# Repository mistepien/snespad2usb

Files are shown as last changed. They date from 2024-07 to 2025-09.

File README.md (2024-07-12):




# snespad2usb
SNES gampepad adapter to USB.

<a href="https://github.com/mistepien/snespad2usb/blob/main/snespad2usb.pdf">Adapter</a> is actually a shield for 
<a href="https://learn.sparkfun.com/tutorials/pro-micro--fio-v3-hookup-guide/hardware-overview-pro-micro">Arduino Pro Micro based on ATmega 32U4</a>.

ATmega 32U4 has a hardware support for fullspeed USB, thus <a href="https://wiki.archlinux.org/title/mouse_polling_rate">polling rate 1000Hz</a> is not an issue for that chip.

You can use the <a href="https://github.com/mistepien/snespad2usb/tree/main/production">gerber file<a> to order the PCB.

Attached <a href="https://github.com/mistepien/snespad2usb/tree/main/firmware">code</a> uses port registers so that is quite efficient. The code was tested with <a href="https://www.8bitdo.com/sn30-wireless-for-original-snes-sfc/">SN30 2.4g wireless gamepad for original SNES/SFC</a> and original SNES and SFC gamepads. Everything works flawless!

One footprint is not trivial: SNES gamapad socket (<b>J1</b>). Footprint is DIY.

<b>J2</b> is redundant -- you can use it to add some new features like autofire switch or sth.

Sometimes during uploading code to Arduino board you may face some issues -- then you will need to use RESET -- so <b>SW1</b> can be useful if you like to develope your own code.

SW2 can be usefull to have a so-called "Hot key" -- you can need it eg. in Batocera.

LED D1 shows is SNES gamepad connected at all. LED D2 is just a status LED (turn on in setup() function of firmware).

BOM:
| Qty	| Reference(s) | Description |
|-----|---|---|
|2 | D1, D2 | LEDs 3mm |  
|1 | J1| SNES gamepad make connector |
|1 | J2| 2x4 Pinheader. pitch terminal: 2.54mm |
|1 | R1, R2 | resistors for D1 and D2 |
|1 | R3 | 10KΩ PULL-UP resistor for DATA gamepad pin |
|1 | SW1,SW2 | Tact switches from Arduino breadboard projects |
|1 | U1 | DIP20 socket (width 15.24mm) + <a href="https://learn.sparkfun.com/tutorials/pro-micro--fio-v3-hookup-guide/hardware-overview-pro-micro">Arduino Pro Micro</a> |

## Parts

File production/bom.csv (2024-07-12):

Designator | Footprint | Quantity | Value | LCSC Part #
D1 | LED_D3.0mm_Oval | 1 | CTL-ON
D2 | LED_D3.0mm_Oval | 1 | STATUS
J1 | SNES_gamepad_connector_L_horizontal | 1 | SNES-GAMEPAD-SOCKET
J2 | PinHeader_2x04_P2.54mm_Vertical | 1 | Conn_02x04_Odd_Even
R1, R2 | R_Axial_DIN0207_L6.3mm_D2.5mm_P10.16mm_Horizontal_Oval | 2 | RxΩ
R3 | R_Axial_DIN0207_L6.3mm_D2.5mm_P10.16mm_Horizontal_Oval | 1 | R10KΩ
SW1 | SW_PUSH_6mm_H4.3mm | 1 | RST
SW2 | SW_PUSH_6mm_H4.3mm | 1 | HOT KEY
U1 | DIP-24_W15.24mm_Socket_LongPads | 1 | Arduino_Pro_Micro

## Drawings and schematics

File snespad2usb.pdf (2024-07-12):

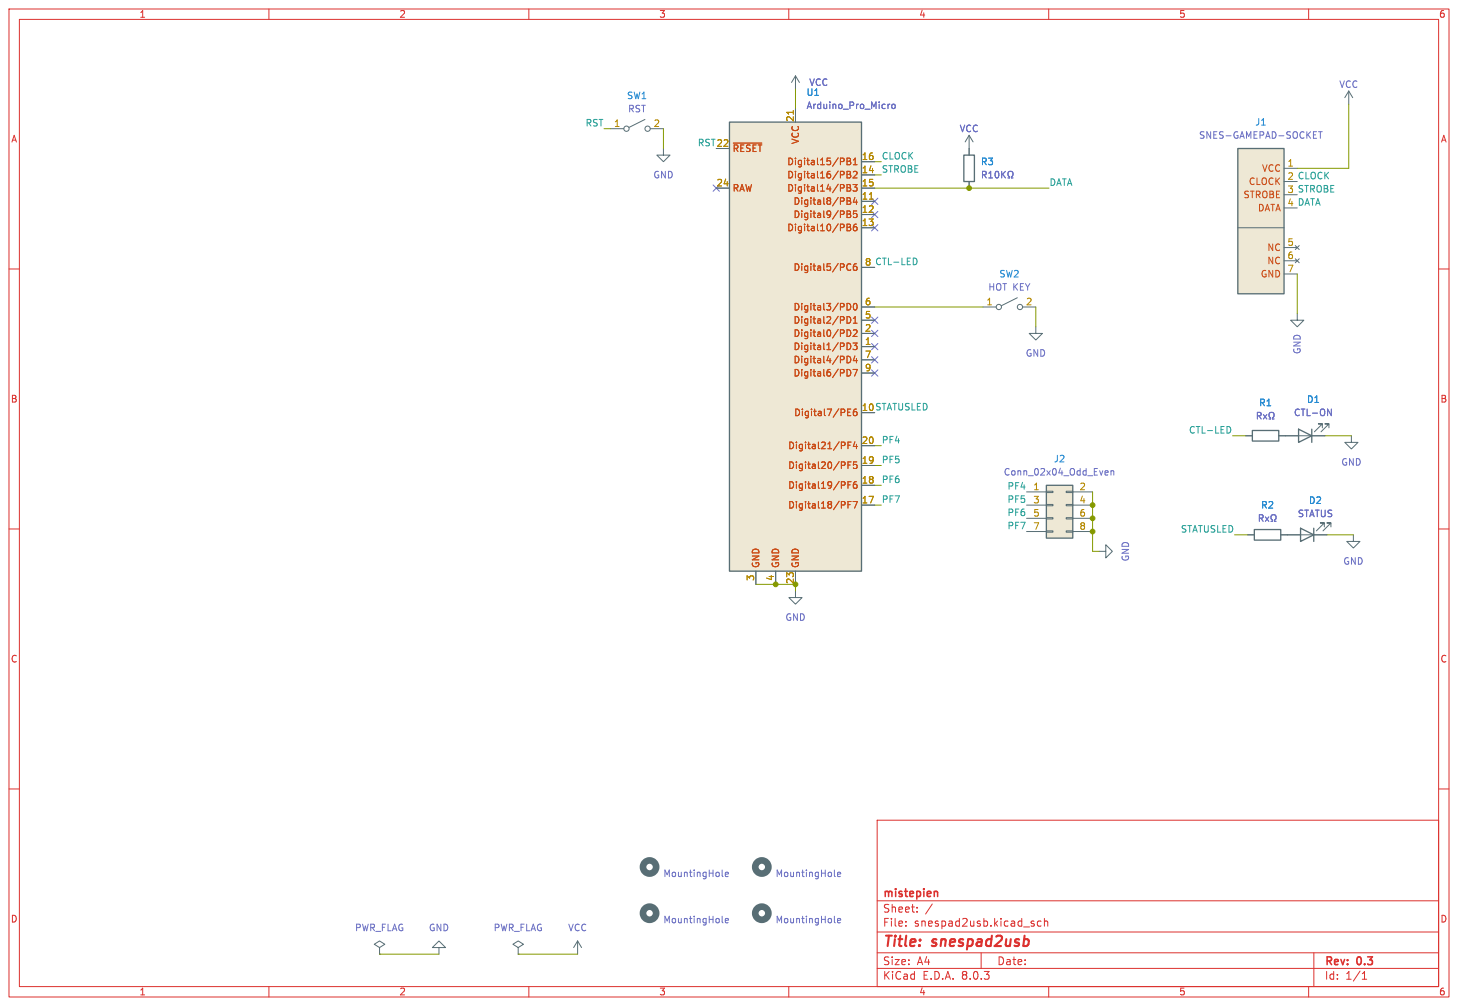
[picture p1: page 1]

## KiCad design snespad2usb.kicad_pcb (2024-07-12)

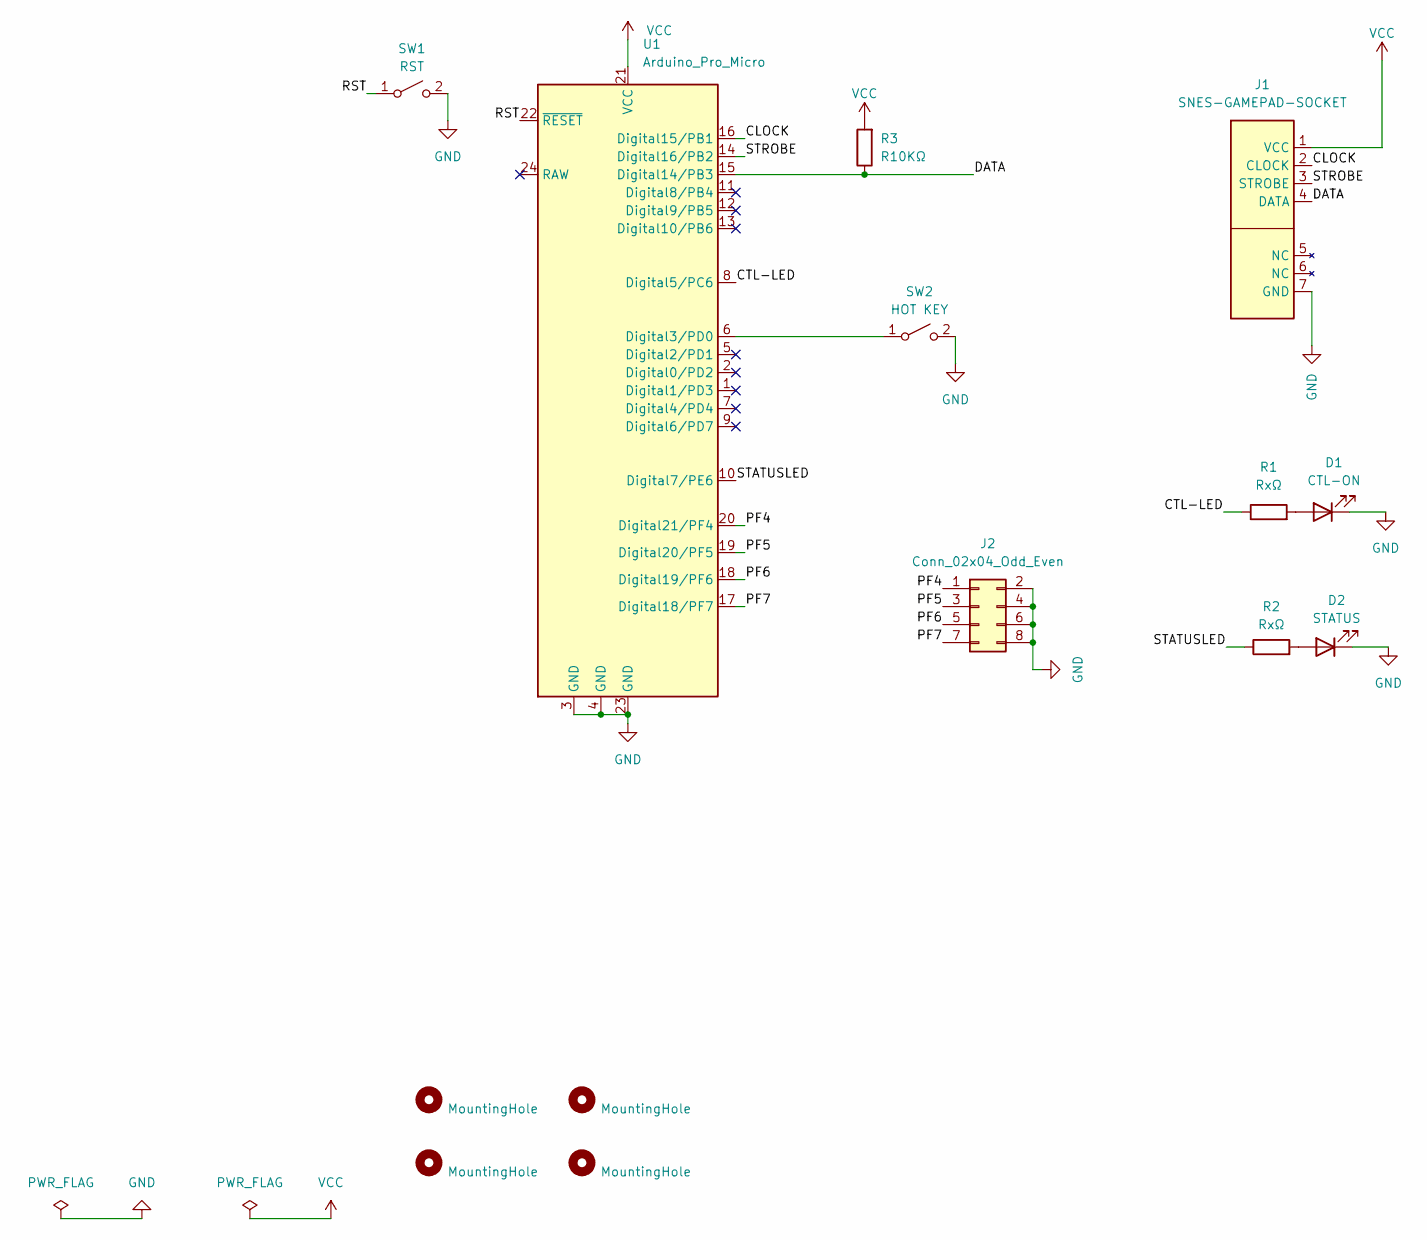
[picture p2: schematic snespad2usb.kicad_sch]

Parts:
D1: CTL-ON; LED_D3.0mm_Oval
D2: STATUS; LED_D3.0mm_Oval
H1, H2, H3, H4: MountingHole; MountingHole_3.5mm
J1: SNES-GAMEPAD-SOCKET; SNES_gamepad_connector_L_horizontal
J2: Conn_02x04_Odd_Even; PinHeader_2x04_P2.54mm_Vertical
R1, R2: RxΩ; R_Axial_DIN0207_L6.3mm_D2.5mm_P10.16mm_Horizontal_Oval
R3: R10KΩ; R_Axial_DIN0207_L6.3mm_D2.5mm_P10.16mm_Horizontal_Oval
SW1: RST; SW_PUSH_6mm_H4.3mm
SW2: HOT KEY; SW_PUSH_6mm_H4.3mm
U1: Arduino_Pro_Micro; DIP-24_W15.24mm_Socket_LongPads

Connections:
/CLOCK: J1.2 (CLOCK), U1.16 (Digital15/PB1)
/CTL-LED: R1.1, U1.8 (Digital5/PC6)
/DATA: J1.4 (DATA), R3.1, U1.15 (Digital14/PB3)
/PF4: J2.1, U1.20 (Digital21/PF4)
/PF5: J2.3, U1.19 (Digital20/PF5)
/PF6: J2.5, U1.18 (Digital19/PF6)
/PF7: J2.7, U1.17 (Digital18/PF7)
/RST: SW1.1 (A), U1.22 (~RESET)
/STATUSLED: R2.1, U1.10 (Digital7/PE6)
/STROBE: J1.3 (STROBE), U1.14 (Digital16/PB2)
GND: D1.1 (K), D2.1 (K), J1.7 (GND), J2.2, J2.4, J2.6, J2.8, SW1.2 (B), SW2.2 (B), U1.3 (GND), U1.4 (GND), U1.23 (GND)
unnamed: D1.2 (A), R1.2
unnamed: D2.2 (A), R2.2
unnamed: SW2.1 (A), U1.6 (Digital3/PD0)
VCC: J1.1 (VCC), R3.2, U1.21 (VCC)

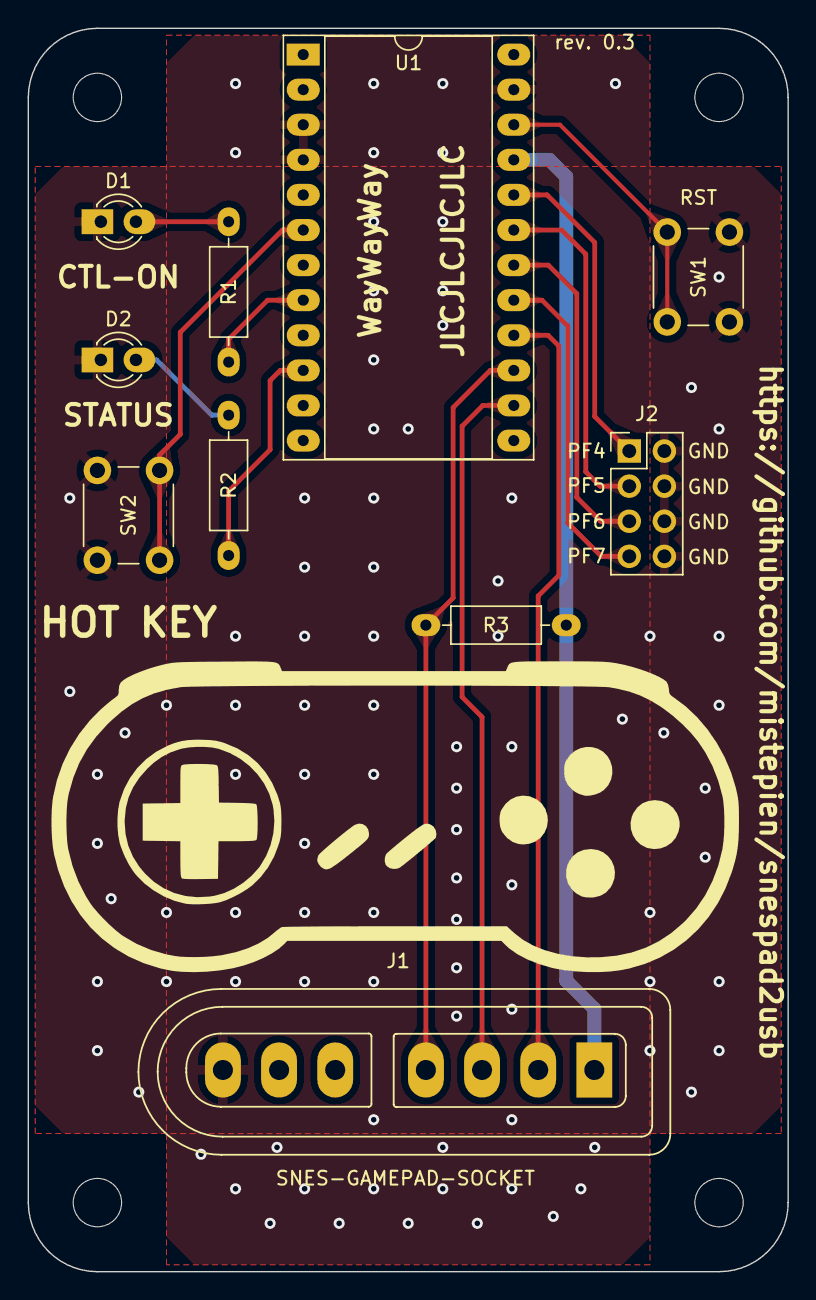
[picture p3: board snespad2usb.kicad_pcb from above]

Board: 2 copper layers, 55.0 x 90.0 mm, 14 parts (0 on the bottom side), 15 nets.

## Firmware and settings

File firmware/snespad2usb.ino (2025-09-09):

#include "SNES.h"


#include <Joystick.h>  //https://github.com/MHeironimus/ArduinoJoystickLibrary
Joystick_ Joystick(JOYSTICK_DEFAULT_REPORT_ID, JOYSTICK_TYPE_JOYSTICK,
                   9, 0,                  // Button Count, Hat Switch Count
                   true, true, false,     // X and Y, but no Z Axis
                   false, false, false,   // No Rx, Ry, or Rz
                   false, false,          // No rudder or throttle
                   false, false, false);  // No accelerator, brake, or steering

void setup() {
  bitSet(DDRE, 6);
  bitClear(PORTE, 6);  //STATUS LED - OFF
  snes.begin(1, 2, 3);

  Joystick.setXAxisRange(-1, 1);
  Joystick.setYAxisRange(-1, 1);
  Joystick.begin(false);
  Joystick.setXAxis(0);
  Joystick.setYAxis(0);

  delay(1500); /*very ugly and dirty hack
                without that delay() joystick will not
                be centered at the beginning (that is an
                issue with Joystick.sendState();
*/


  /*turn off RX and TX LEDS on permanent basis

    turning off these LEDS here at the end of setup()
    is an indicator that joy2usb is ready
  */

  bitClear(DDRD, 5);
  bitClear(DDRB, 0);

  bitSet(DDRC, 6);
  bitClear(PORTC, 6);  //CTL-ON LED - OFF
  bitSet(PORTE, 6);    //STATUS LED - ON

  bitClear(DDRD, 0);
  bitSet(PORTD, 0);

  Joystick.sendState();
}

byte DPAD_UP;
byte DPAD_DOWN;
byte DPAD_LEFT;
byte DPAD_RIGHT;

void button(byte btn, bool btn_state) {
  switch (btn) {
    case SNES_CTL_ON:
      bitWrite(PORTC, 6, btn_state);  //CTL-ON LED
      break;
    case SNES_BTN_SELECT:
      Joystick.setButton(0, btn_state);
      break;
    case SNES_BTN_START:
      Joystick.setButton(1, btn_state);
      break;
    case SNES_DPAD_UP:
      DPAD_UP = btn_state;
      break;
    case SNES_DPAD_DOWN:
      DPAD_DOWN = btn_state;
      break;
    case SNES_DPAD_LEFT:
      DPAD_LEFT = btn_state;
      break;
    case SNES_DPAD_RIGHT:
      DPAD_RIGHT = btn_state;
      break;
    case SNES_BTN_A:
      Joystick.setButton(2, btn_state);
      break;
    case SNES_BTN_X:
      Joystick.setButton(3, btn_state);
      break;
    case SNES_BTN_B:
      Joystick.setButton(4, btn_state);
      break;
    case SNES_BTN_Y:
      Joystick.setButton(5, btn_state);
      break;
    case SNES_BTN_TL:
      Joystick.setButton(6, btn_state);
      break;
    case SNES_BTN_TR:
      Joystick.setButton(7, btn_state);
      break;
  }
}

constexpr byte hotkey_debounce_time_MS = 100;

void send_state(word _current_state) {
  static word prev_state;
  word changed_state = prev_state ^ _current_state;
  if (changed_state) {
    prev_state = _current_state;
    for (byte index = 0; index < 13; index++) {
      if (bitRead(changed_state, index)) {
        button(index, bitRead(_current_state, index));
      }
    }
    Joystick.setYAxis(DPAD_DOWN - DPAD_UP);
    Joystick.setXAxis(DPAD_RIGHT - DPAD_LEFT);
  }

  static unsigned long prev_hotkey_time;
  static bool prev_hotkey_state;
  bool current_hotkey_state = 1 ^ bitRead(PIND, 0);
  if (current_hotkey_state ^ prev_hotkey_state) {
    unsigned long current_hotkey_time = millis();
    if (current_hotkey_time - prev_hotkey_time > hotkey_debounce_time_MS) {
      prev_hotkey_state = current_hotkey_state;
      prev_hotkey_time = current_hotkey_time;
      Joystick.setButton(8, current_hotkey_state);
    }
  }
  Joystick.sendState();  //ONE common send.State for AXISES AND BUTTONS
}

void loop() {
  while (true) {
    send_state(snes.getState());
  }
}

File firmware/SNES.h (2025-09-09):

#ifndef SNES_h
#define SNES_h

#define PORT_REG PORTB
#define DDR_REG DDRB
#define PIN_REG PINB

const unsigned long SNES_DELAYSTD_US = 6;
#define SNES_READ_DELAY_MS 4

enum snes_state {
  SNES_CTL_ON = 0,  // The controller is connected
  SNES_BTN_SELECT = 1,
  SNES_BTN_START = 2,
  SNES_DPAD_UP = 3,
  SNES_DPAD_DOWN = 4,
  SNES_DPAD_LEFT = 5,
  SNES_DPAD_RIGHT = 6,
  SNES_BTN_A = 7,
  SNES_BTN_X = 8,
  SNES_BTN_B = 9,
  SNES_BTN_Y = 10,
  SNES_BTN_TL = 11,
  SNES_BTN_TR = 12
};

constexpr word btr_snes_output_bits[17] = {
  bit(SNES_BTN_B),
  bit(SNES_BTN_Y),
  bit(SNES_BTN_SELECT),
  bit(SNES_BTN_START),
  bit(SNES_DPAD_UP),
  bit(SNES_DPAD_DOWN),
  bit(SNES_DPAD_LEFT),
  bit(SNES_DPAD_RIGHT),
  bit(SNES_BTN_A),
  bit(SNES_BTN_X),
  bit(SNES_BTN_TL),
  bit(SNES_BTN_TR),
  0, 0, 0, 0,
  bit(SNES_CTL_ON)
};

class SNESClass {
private:
  byte _clockPin_bit;
  byte _strobePin_bit;
  byte _dataPin_bit;
  word update();
  word shiftInSNES();
public:
  void begin(byte clockPin, byte strobePin, byte dataPin);
  word getState();
  word nod(word _input_state, word _dpad_dirs);
};

extern SNESClass snes;

#endif
